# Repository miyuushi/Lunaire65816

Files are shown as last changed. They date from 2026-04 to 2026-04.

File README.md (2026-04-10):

# Lunaire65816

My 16-bit retro computer I designed from scratch. It's centered around a 65816 CPU and uses classic components with FPGA-based glue logic, hardware FM sound, and modern display output.

## Features

- 65816 16-bit CPU
- Custom PCB design
- FPGA for glue logic and video generation
- YM3812 FM synthesis sound chip
- Dual VIA chips for I/O
- SNES controller headers
- PS/2 keyboard interface
- VGA output

## Architecture Overview

- CPU: WDC 65816
- Sound: YM3812 (OPL2)
- I/O: Two VIA chips
- Video: VGA generated using FPGA logic
- Input:
  - SNES controller ports
  - PS/2 keyboard
- Address decoding: GAL
- Board: Custom PCB

## Memory Map

Address decoding is handled by a GAL chip.

### 6502 Emulation Mode

- 48K RAM
- 4K I/O
- 12K ROM

This mode is useful for compatibility and early bring-up.

### 65816 Native Mode

- 4MB RAM
- 4K I/O (expandable, may increase later)
- 12K ROM

Native mode enables the full 24-bit address space of the 65816.

## Audio

The system uses a YM3812 (OPL2) FM synthesis chip for hardware-generated sound.

## Input

- SNES controller headers for gamepad input
- PS/2 keyboard support

## Video (unimplemented)

VGA output is generated through FPGA logic. The goal is compatibility with modern monitors. 

## Screenshots

Hardware:
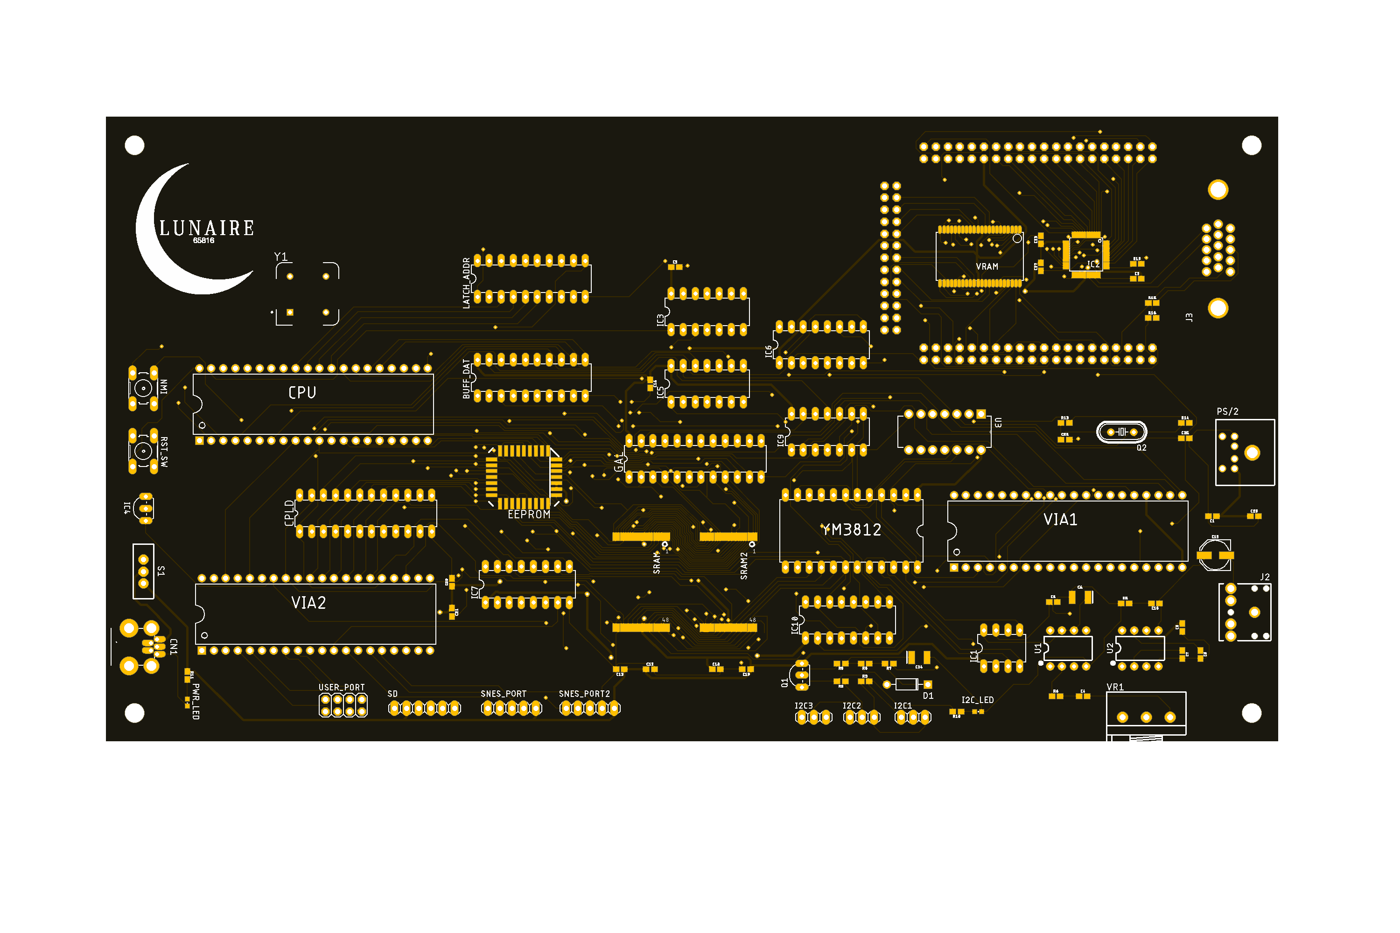
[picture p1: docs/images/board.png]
Board


## Hardware Design Notes

- Custom PCB layout
- Discrete retro components
- FPGA used for glue logic and video
- GAL used for address decoding
- VIA chips provide timers and general-purpose I/O

## Status

Work in progress. Basic hardware is assembled and bring-up is ongoing.

## License

This project is licensed under the GNU Lesser General Public License v3.0 or later.

See the LICENSE file for details.

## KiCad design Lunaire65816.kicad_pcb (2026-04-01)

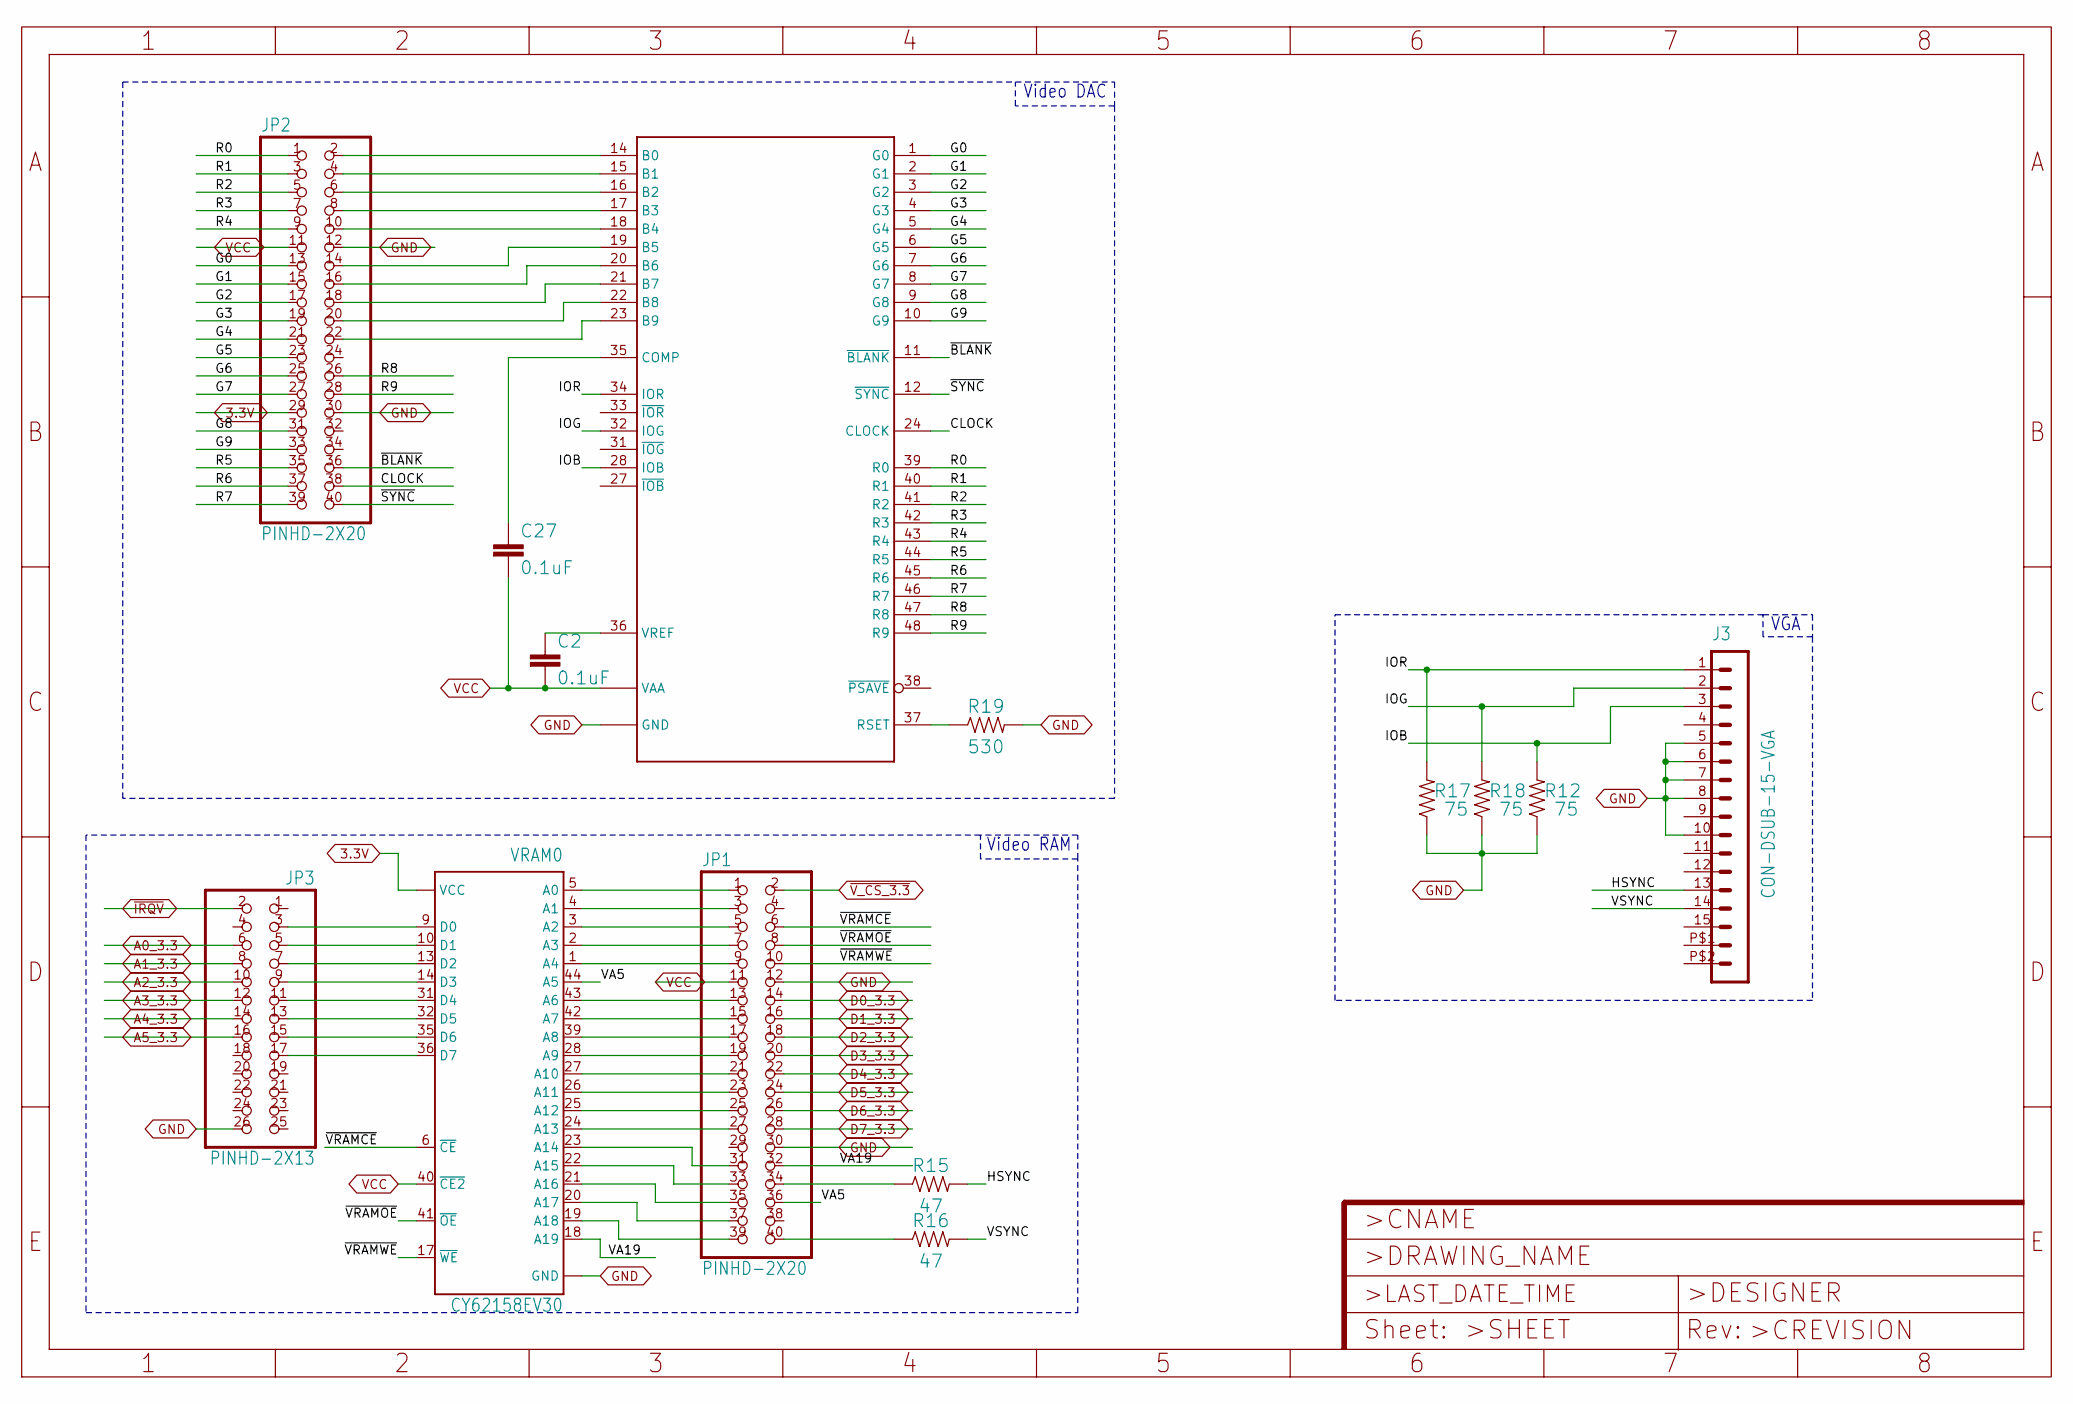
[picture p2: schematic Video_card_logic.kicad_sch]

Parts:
C2, C27: 0.1uF; 0603
IC2: ADV7123; LQFP48
J3: CON-DSUB-15-VGA; 181-015-212-171
JP1, JP2: PINHD-2X20; 2X20
JP3: PINHD-2X13; 2X13
R12, R17, R18: 75; 0603
R15, R16: 47; 0603
R19: 530; 0603
VRAM0: CY62158EV30; TSOP-II-44

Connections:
3.3V: JP2.29, VRAM0.11 (VCC), VRAM0.33 (VCC); also elsewhere on the board
A0_3.3: JP3.6; also elsewhere on the board
A1_3.3: JP3.8; also elsewhere on the board
A2_3.3: JP3.10; also elsewhere on the board
A3_3.3: JP3.12; also elsewhere on the board
A4_3.3: JP3.14; also elsewhere on the board
A5_3.3: JP3.16; also elsewhere on the board
CLOCK: IC2.24 (CLOCK), JP2.38
D0_3.3: JP1.14; also elsewhere on the board
D1_3.3: JP1.16; also elsewhere on the board
D2_3.3: JP1.18; also elsewhere on the board
D3_3.3: JP1.20; also elsewhere on the board
D4_3.3: JP1.22; also elsewhere on the board
D5_3.3: JP1.24; also elsewhere on the board
D6_3.3: JP1.26; also elsewhere on the board
D7_3.3: JP1.28; also elsewhere on the board
G0: IC2.1 (G0), JP2.13
G1: IC2.2 (G1), JP2.15
G2: IC2.3 (G2), JP2.17
G3: IC2.4 (G3), JP2.19
G4: IC2.5 (G4), JP2.21
G5: IC2.6 (G5), JP2.23
G6: IC2.7 (G6), JP2.25
G7: IC2.8 (G7), JP2.27
G8: IC2.9 (G8), JP2.31
G9: IC2.10 (G9), JP2.33
GND: IC2.25 (GND), IC2.26 (GND), J3.5, J3.6, J3.7, J3.8, J3.10, JP1.12, JP1.30, JP2.12, JP2.30, JP3.26, R12.1, R17.1, R18.1, R19.2, VRAM0.12 (GND), VRAM0.34 (GND); also elsewhere on the board
HSYNC: J3.13, R15.2
IOB: IC2.28 (IOB), J3.3, R12.2
IOG: IC2.32 (IOG), J3.2, R18.2
IOR: IC2.34 (IOR), J3.1, R17.2
unnamed: JP1.35, VRAM0.21 (A16)
unnamed: JP1.33, VRAM0.22 (A15)
unnamed: JP1.31, VRAM0.23 (A14)
unnamed: JP1.27, VRAM0.24 (A13)
unnamed: IC2.37 (RSET), R19.1
unnamed: C2.1, IC2.36 (VREF)
unnamed: JP1.37, VRAM0.20 (A17)
unnamed: IC2.14 (B0), JP2.2
unnamed: IC2.15 (B1), JP2.4
unnamed: IC2.16 (B2), JP2.6
unnamed: IC2.17 (B3), JP2.8
unnamed: IC2.18 (B4), JP2.10
unnamed: IC2.19 (B5), JP2.14
unnamed: IC2.20 (B6), JP2.16
unnamed: IC2.21 (B7), JP2.18
unnamed: IC2.22 (B8), JP2.20
unnamed: IC2.23 (B9), JP2.22
unnamed: C27.1, IC2.35 (COMP)
unnamed: JP1.40, R16.1
unnamed: JP1.34, R15.1
unnamed: JP1.25, VRAM0.25 (A12)
unnamed: JP1.23, VRAM0.26 (A11)
unnamed: JP1.21, VRAM0.27 (A10)
unnamed: JP1.19, VRAM0.28 (A9)
unnamed: JP1.17, VRAM0.39 (A8)
unnamed: JP1.15, VRAM0.42 (A7)
unnamed: JP1.13, VRAM0.43 (A6)
unnamed: JP1.9, VRAM0.1 (A4)
unnamed: JP1.7, VRAM0.2 (A3)
unnamed: JP1.5, VRAM0.3 (A2)
unnamed: JP3.17, VRAM0.36 (D7)
unnamed: JP3.15, VRAM0.35 (D6)
unnamed: JP3.13, VRAM0.32 (D5)
unnamed: JP3.11, VRAM0.31 (D4)
unnamed: JP3.9, VRAM0.14 (D3)
unnamed: JP3.7, VRAM0.13 (D2)
unnamed: JP3.5, VRAM0.10 (D1)
unnamed: JP3.3, VRAM0.9 (D0)
unnamed: JP1.39, VRAM0.19 (A18)
unnamed: JP1.3, VRAM0.4 (A1)
unnamed: JP1.1, VRAM0.5 (A0)
R0: IC2.39 (R0), JP2.1
R1: IC2.40 (R1), JP2.3
R2: IC2.41 (R2), JP2.5
R3: IC2.42 (R3), JP2.7
R4: IC2.43 (R4), JP2.9
R5: IC2.44 (R5), JP2.35
R6: IC2.45 (R6), JP2.37
R7: IC2.46 (R7), JP2.39
R8: IC2.47 (R8), JP2.26
R9: IC2.48 (R9), JP2.28
VA5: JP1.36, VRAM0.44 (A5)
VA19: JP1.32, VRAM0.18 (A19)
VCC: C2.2, C27.2, IC2.13 (VAA), IC2.29 (VAA), IC2.30 (VAA), JP1.11, JP2.11, VRAM0.40 (~CE2); also elsewhere on the board
VSYNC: J3.14, R16.2
~BLANK: IC2.11 (~BLANK), JP2.36
~IRQV: JP3.2; also elsewhere on the board
~SYNC: IC2.12 (~SYNC), JP2.40
~VRAMCE: JP1.6, VRAM0.6 (~CE)
~VRAMOE: JP1.8, VRAM0.41 (~OE)
~VRAMWE: JP1.10, VRAM0.17 (~WE)
~V_CS_3.3: JP1.2; also elsewhere on the board

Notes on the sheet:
VGA
Video DAC
Video RAM

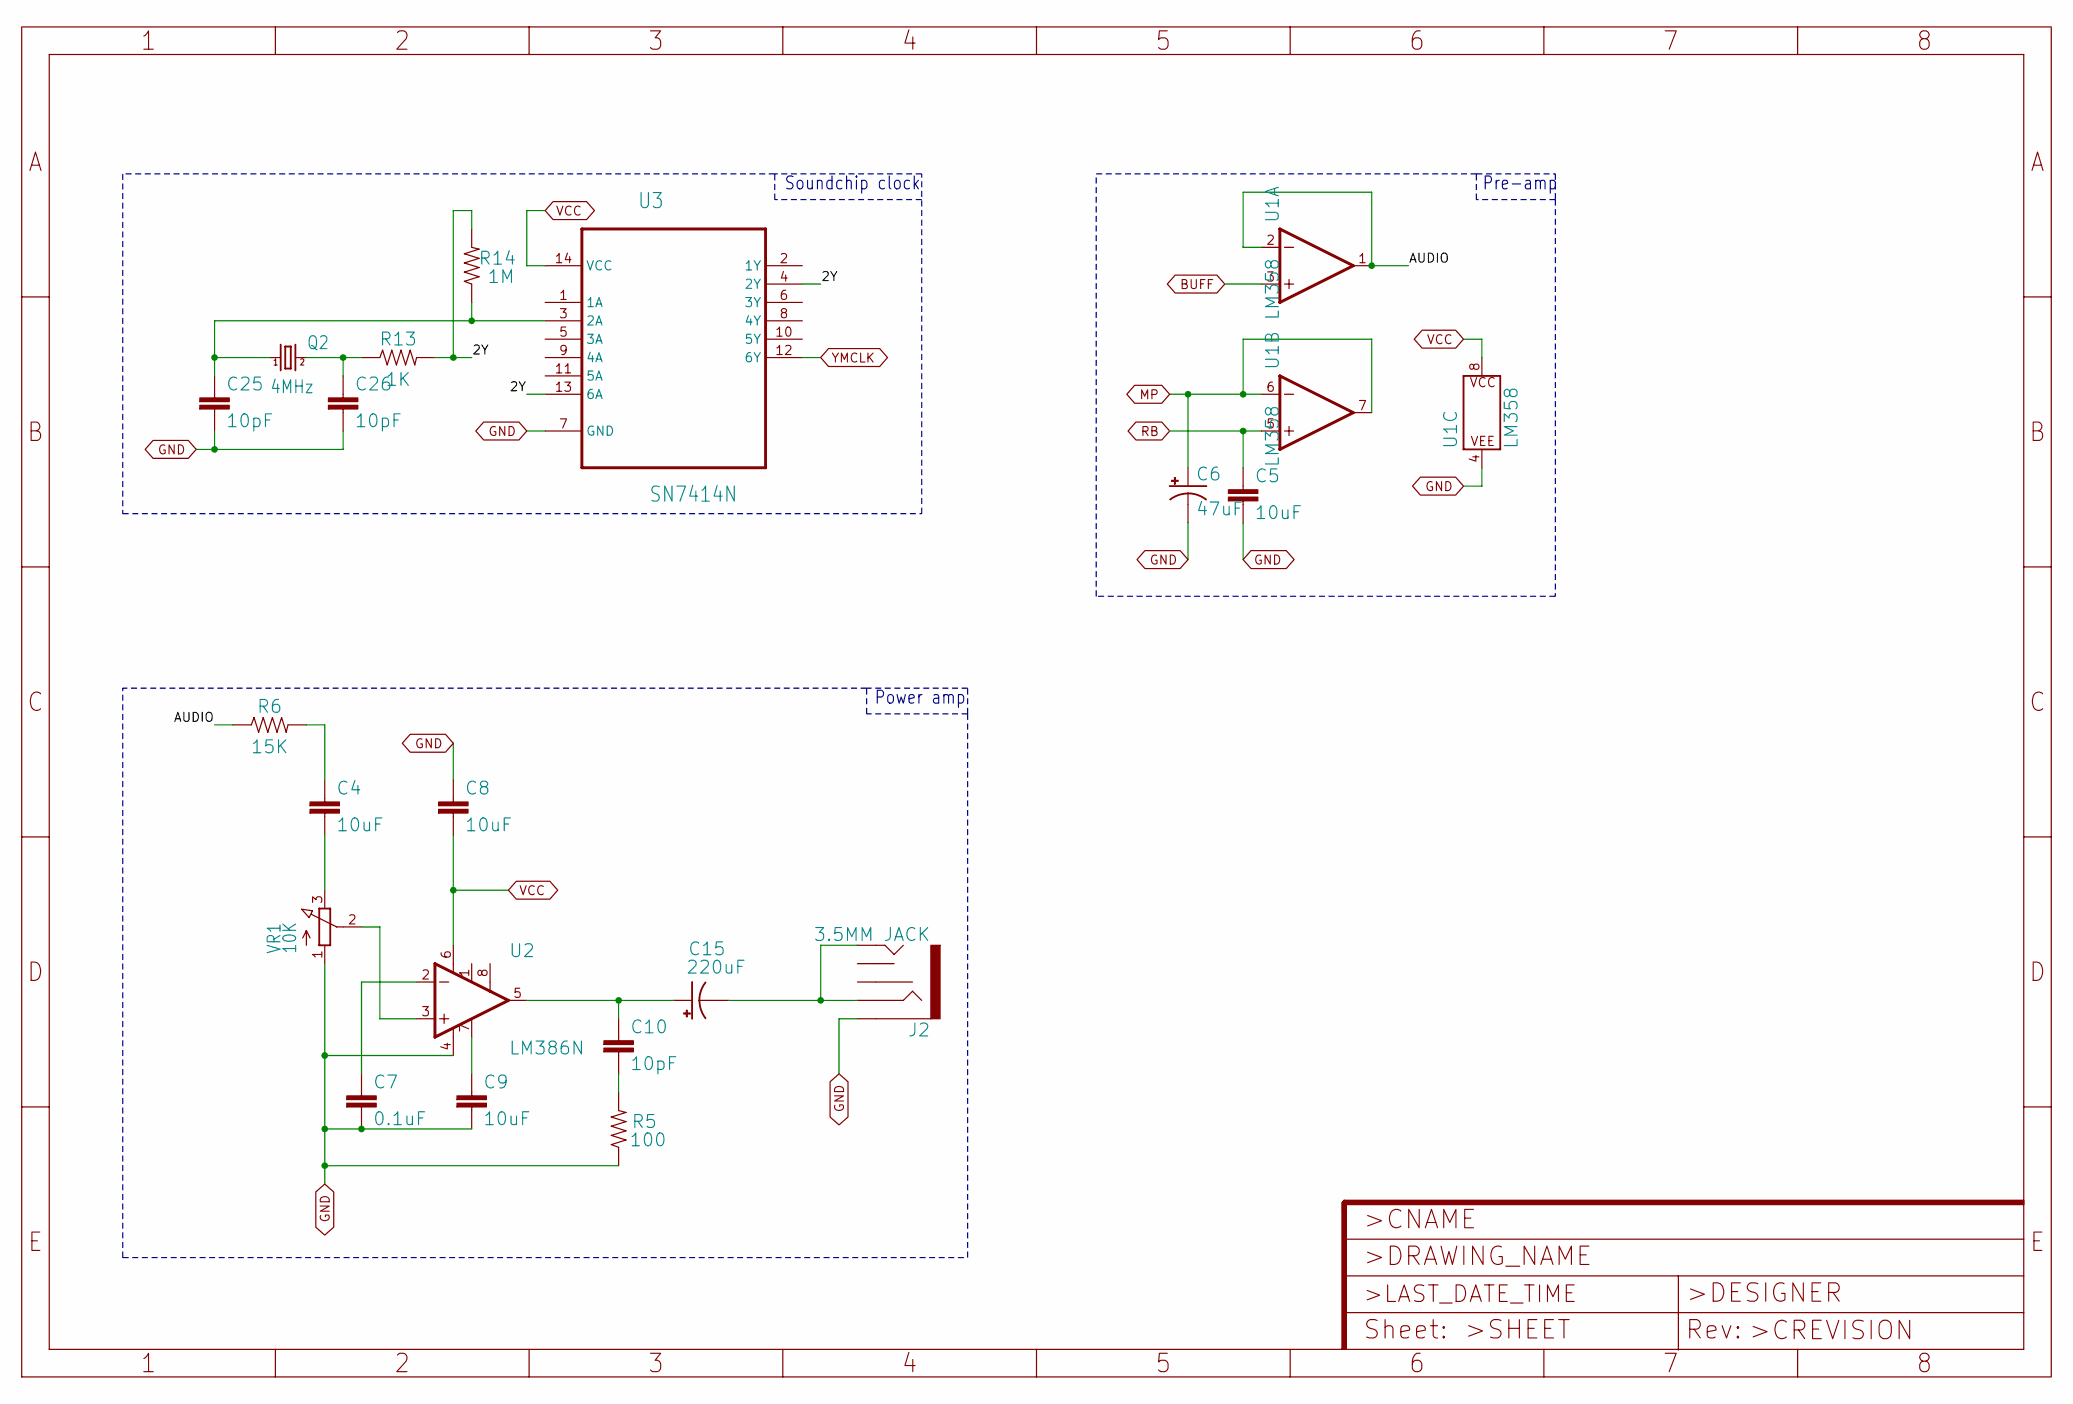
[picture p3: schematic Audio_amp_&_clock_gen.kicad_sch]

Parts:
C4, C5, C8, C9: 10uF; 0603
C6: 47uF; EIA3528
C7: 0.1uF; 0603
C10, C25, C26: 10pF; 0603
C15: 220uF; PANASONIC_D
J2: 3.5MM JACK; AUDIO-JACK
Q2: 4MHz; HC49_S
R5: 100; 0603
R6: 15K; 0603
R13: 1K; 0603
R14: 1M; 0603
U1: LM358; DIP08
U2: LM386N; DIP08
U3: SN7414N; DIP254P762X508-14
VR1: 10K; 3RP_1610N

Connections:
2Y: R13.2, R14.2, U3.4 (2Y), U3.13 (6A)
AUDIO: R6.1, U1.1 (OUT), U1.2 (-IN)
BUFF: U1.3 (+IN); also elsewhere on the board
GND: C5.2, C6.C (-), C7.2, C8.1, C9.2, C25.2, C26.2, J2.SLEEVE, R5.1, U1.4 (P$V-), U2.4 (V-), U3.7 (GND), VR1.1 (A); also elsewhere on the board
MP: C6.A (+), U1.6 (-IN), U1.7 (OUT); also elsewhere on the board
unnamed: C7.1, U2.2 (-IN)
unnamed: C4.1, R6.2
unnamed: C4.2, VR1.3 (E)
unnamed: U2.3 (+IN), VR1.2 (S)
unnamed: C9.1, U2.7 (BP)
unnamed: C10.1, C15.+, U2.5 (OUT)
unnamed: C10.2, R5.2
unnamed: C15.-, J2.RING, J2.TIP
unnamed: C25.1, Q2.1, R14.1, U3.3 (2A)
unnamed: C26.1, Q2.2, R13.1
RB: C5.1, U1.5 (+IN); also elsewhere on the board
VCC: C8.2, U1.8 (P$V+), U2.6 (V+), U3.14 (VCC); also elsewhere on the board
YMCLK: U3.12 (6Y); also elsewhere on the board

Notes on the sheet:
Power amp
Soundchip clock
Pre-amp

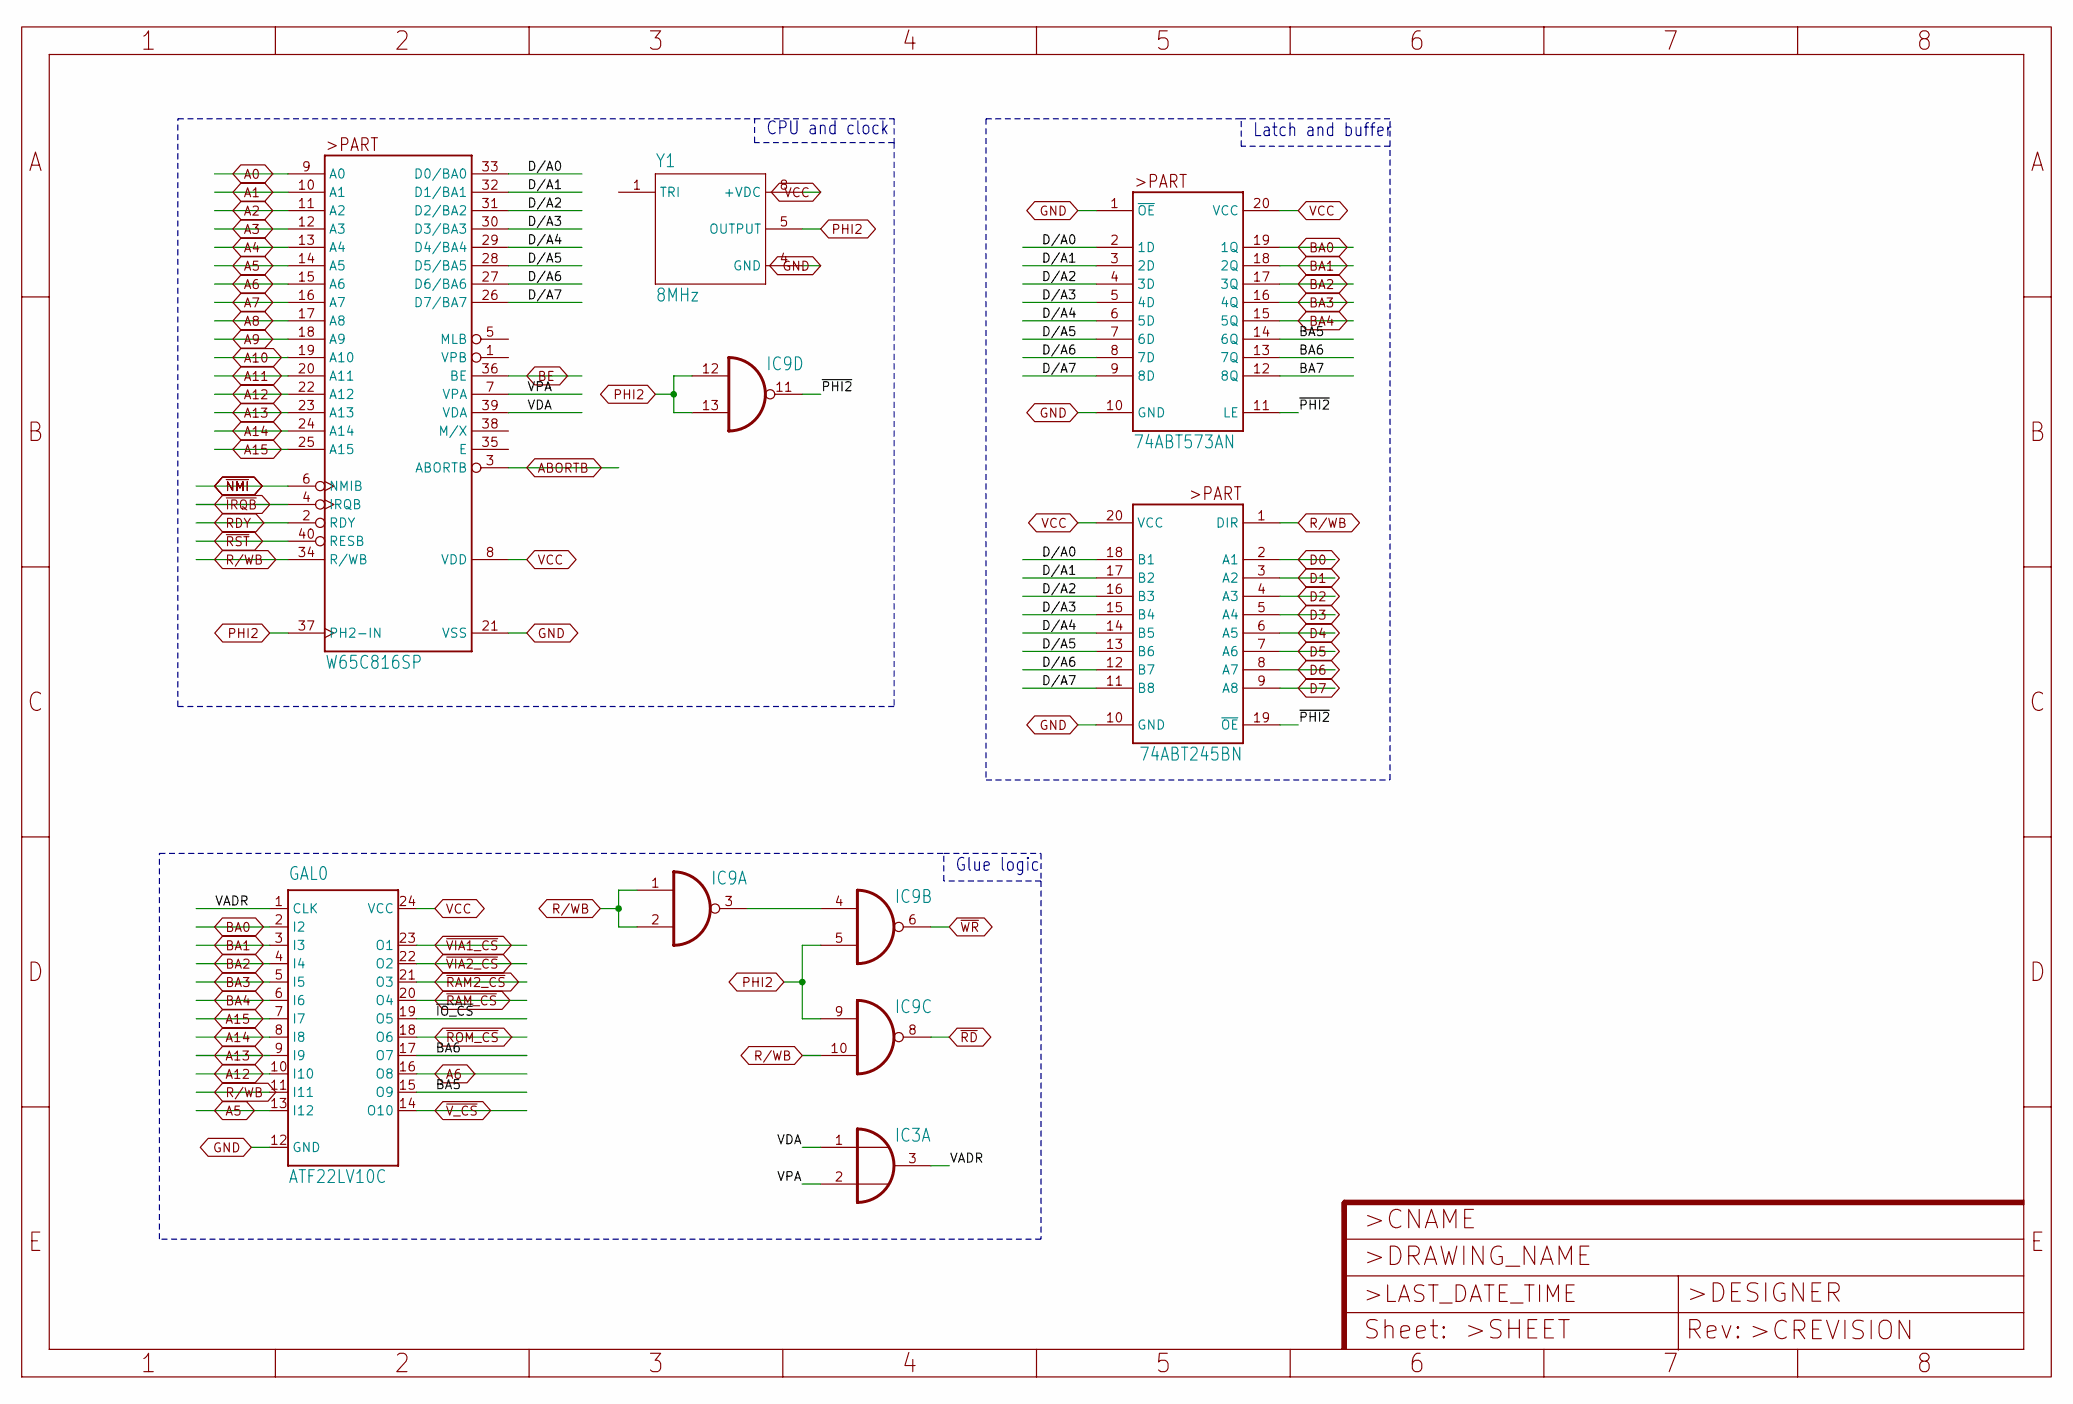
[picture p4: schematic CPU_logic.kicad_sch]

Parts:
BUFF_DAT0: 74ABT245BN; PDIP20
CPU0: W65C816SP; DIP-40
GAL0: ATF22LV10C; DIL24-3
IC3: 7432N; DIL14
IC9: 7400N; DIL14
LATCH_ADDR0: 74ABT573AN; PDIP20
Y1: 8MHz; OSC_ECS-2200B-110.5

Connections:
A0: CPU0.9 (A0); also elsewhere on the board
A1: CPU0.10 (A1); also elsewhere on the board
A2: CPU0.11 (A2); also elsewhere on the board
A3: CPU0.12 (A3); also elsewhere on the board
A4: CPU0.13 (A4); also elsewhere on the board
A5: CPU0.14 (A5), GAL0.13 (I12); also elsewhere on the board
A6: CPU0.15 (A6), GAL0.16 (O8); also elsewhere on the board
A7: CPU0.16 (A7); also elsewhere on the board
A8: CPU0.17 (A8); also elsewhere on the board
A9: CPU0.18 (A9); also elsewhere on the board
A10: CPU0.19 (A10); also elsewhere on the board
A11: CPU0.20 (A11); also elsewhere on the board
A12: CPU0.22 (A12), GAL0.10 (I10); also elsewhere on the board
A13: CPU0.23 (A13), GAL0.9 (I9); also elsewhere on the board
A14: CPU0.24 (A14), GAL0.8 (I8); also elsewhere on the board
A15: CPU0.25 (A15), GAL0.7 (I7); also elsewhere on the board
ABORTB: CPU0.3 (ABORTB); also elsewhere on the board
BA0: GAL0.2 (I2), LATCH_ADDR0.19 (1Q); also elsewhere on the board
BA1: GAL0.3 (I3), LATCH_ADDR0.18 (2Q); also elsewhere on the board
BA2: GAL0.4 (I4), LATCH_ADDR0.17 (3Q); also elsewhere on the board
BA3: GAL0.5 (I5), LATCH_ADDR0.16 (4Q); also elsewhere on the board
BA4: GAL0.6 (I6), LATCH_ADDR0.15 (5Q); also elsewhere on the board
BA5: GAL0.15 (O9), LATCH_ADDR0.14 (6Q)
BA6: GAL0.17 (O7), LATCH_ADDR0.13 (7Q)
BA7: LATCH_ADDR0.12 (8Q)
BE: CPU0.36 (BE); also elsewhere on the board
D0: BUFF_DAT0.2 (A1); also elsewhere on the board
D1: BUFF_DAT0.3 (A2); also elsewhere on the board
D2: BUFF_DAT0.4 (A3); also elsewhere on the board
D3: BUFF_DAT0.5 (A4); also elsewhere on the board
D4: BUFF_DAT0.6 (A5); also elsewhere on the board
D5: BUFF_DAT0.7 (A6); also elsewhere on the board
D6: BUFF_DAT0.8 (A7); also elsewhere on the board
D7: BUFF_DAT0.9 (A8); also elsewhere on the board
D/A0: BUFF_DAT0.18 (B1), CPU0.33 (D0/BA0), LATCH_ADDR0.2 (1D)
D/A1: BUFF_DAT0.17 (B2), CPU0.32 (D1/BA1), LATCH_ADDR0.3 (2D)
D/A2: BUFF_DAT0.16 (B3), CPU0.31 (D2/BA2), LATCH_ADDR0.4 (3D)
D/A3: BUFF_DAT0.15 (B4), CPU0.30 (D3/BA3), LATCH_ADDR0.5 (4D)
D/A4: BUFF_DAT0.14 (B5), CPU0.29 (D4/BA4), LATCH_ADDR0.6 (5D)
D/A5: BUFF_DAT0.13 (B6), CPU0.28 (D5/BA5), LATCH_ADDR0.7 (6D)
D/A6: BUFF_DAT0.12 (B7), CPU0.27 (D6/BA6), LATCH_ADDR0.8 (7D)
D/A7: BUFF_DAT0.11 (B8), CPU0.26 (D7/BA7), LATCH_ADDR0.9 (8D)
GND: BUFF_DAT0.10 (GND), CPU0.21 (VSS), GAL0.12 (GND), IC3.7 (GND), IC9.7 (GND), LATCH_ADDR0.1 (~OE), LATCH_ADDR0.10 (GND), Y1.4 (GND); also elsewhere on the board
unnamed: IC9.3 (O), IC9.4 (I0)
PHI2: CPU0.37 (PH2-IN), IC9.5 (I1), IC9.9 (I0), IC9.12 (I0), IC9.13 (I1), Y1.5 (OUTPUT); also elsewhere on the board
R/WB: BUFF_DAT0.1 (DIR), CPU0.34 (R/WB), GAL0.11 (I11), IC9.1 (I0), IC9.2 (I1), IC9.10 (I1); also elsewhere on the board
RDY: CPU0.2 (RDY); also elsewhere on the board
VADR: GAL0.1 (CLK), IC3.3 (O)
VCC: BUFF_DAT0.20 (VCC), CPU0.8 (VDD), GAL0.24 (VCC), IC3.14 (VCC), IC9.14 (VCC), LATCH_ADDR0.20 (VCC), Y1.8 (+VDC); also elsewhere on the board
VDA: CPU0.39 (VDA), IC3.1 (I0)
VPA: CPU0.7 (VPA), IC3.2 (I1)
~IO_CS: GAL0.19 (O5)
~IRQB: CPU0.4 (IRQB); also elsewhere on the board
~NMI: CPU0.6 (NMIB); also elsewhere on the board
~PHI2: BUFF_DAT0.19 (~OE), IC9.11 (O), LATCH_ADDR0.11 (LE)
~RAM2_CS: GAL0.21 (O3); also elsewhere on the board
~RAM_CS: GAL0.20 (O4); also elsewhere on the board
~RD: IC9.8 (O); also elsewhere on the board
~ROM_CS: GAL0.18 (O6); also elsewhere on the board
~RST: CPU0.40 (RESB); also elsewhere on the board
~VIA1_CS: GAL0.23 (O1); also elsewhere on the board
~VIA2_CS: GAL0.22 (O2); also elsewhere on the board
~V_CS: GAL0.14 (O10); also elsewhere on the board
~WR: IC9.6 (O); also elsewhere on the board

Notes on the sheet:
CPU and clock
Latch and buffer
Glue logic

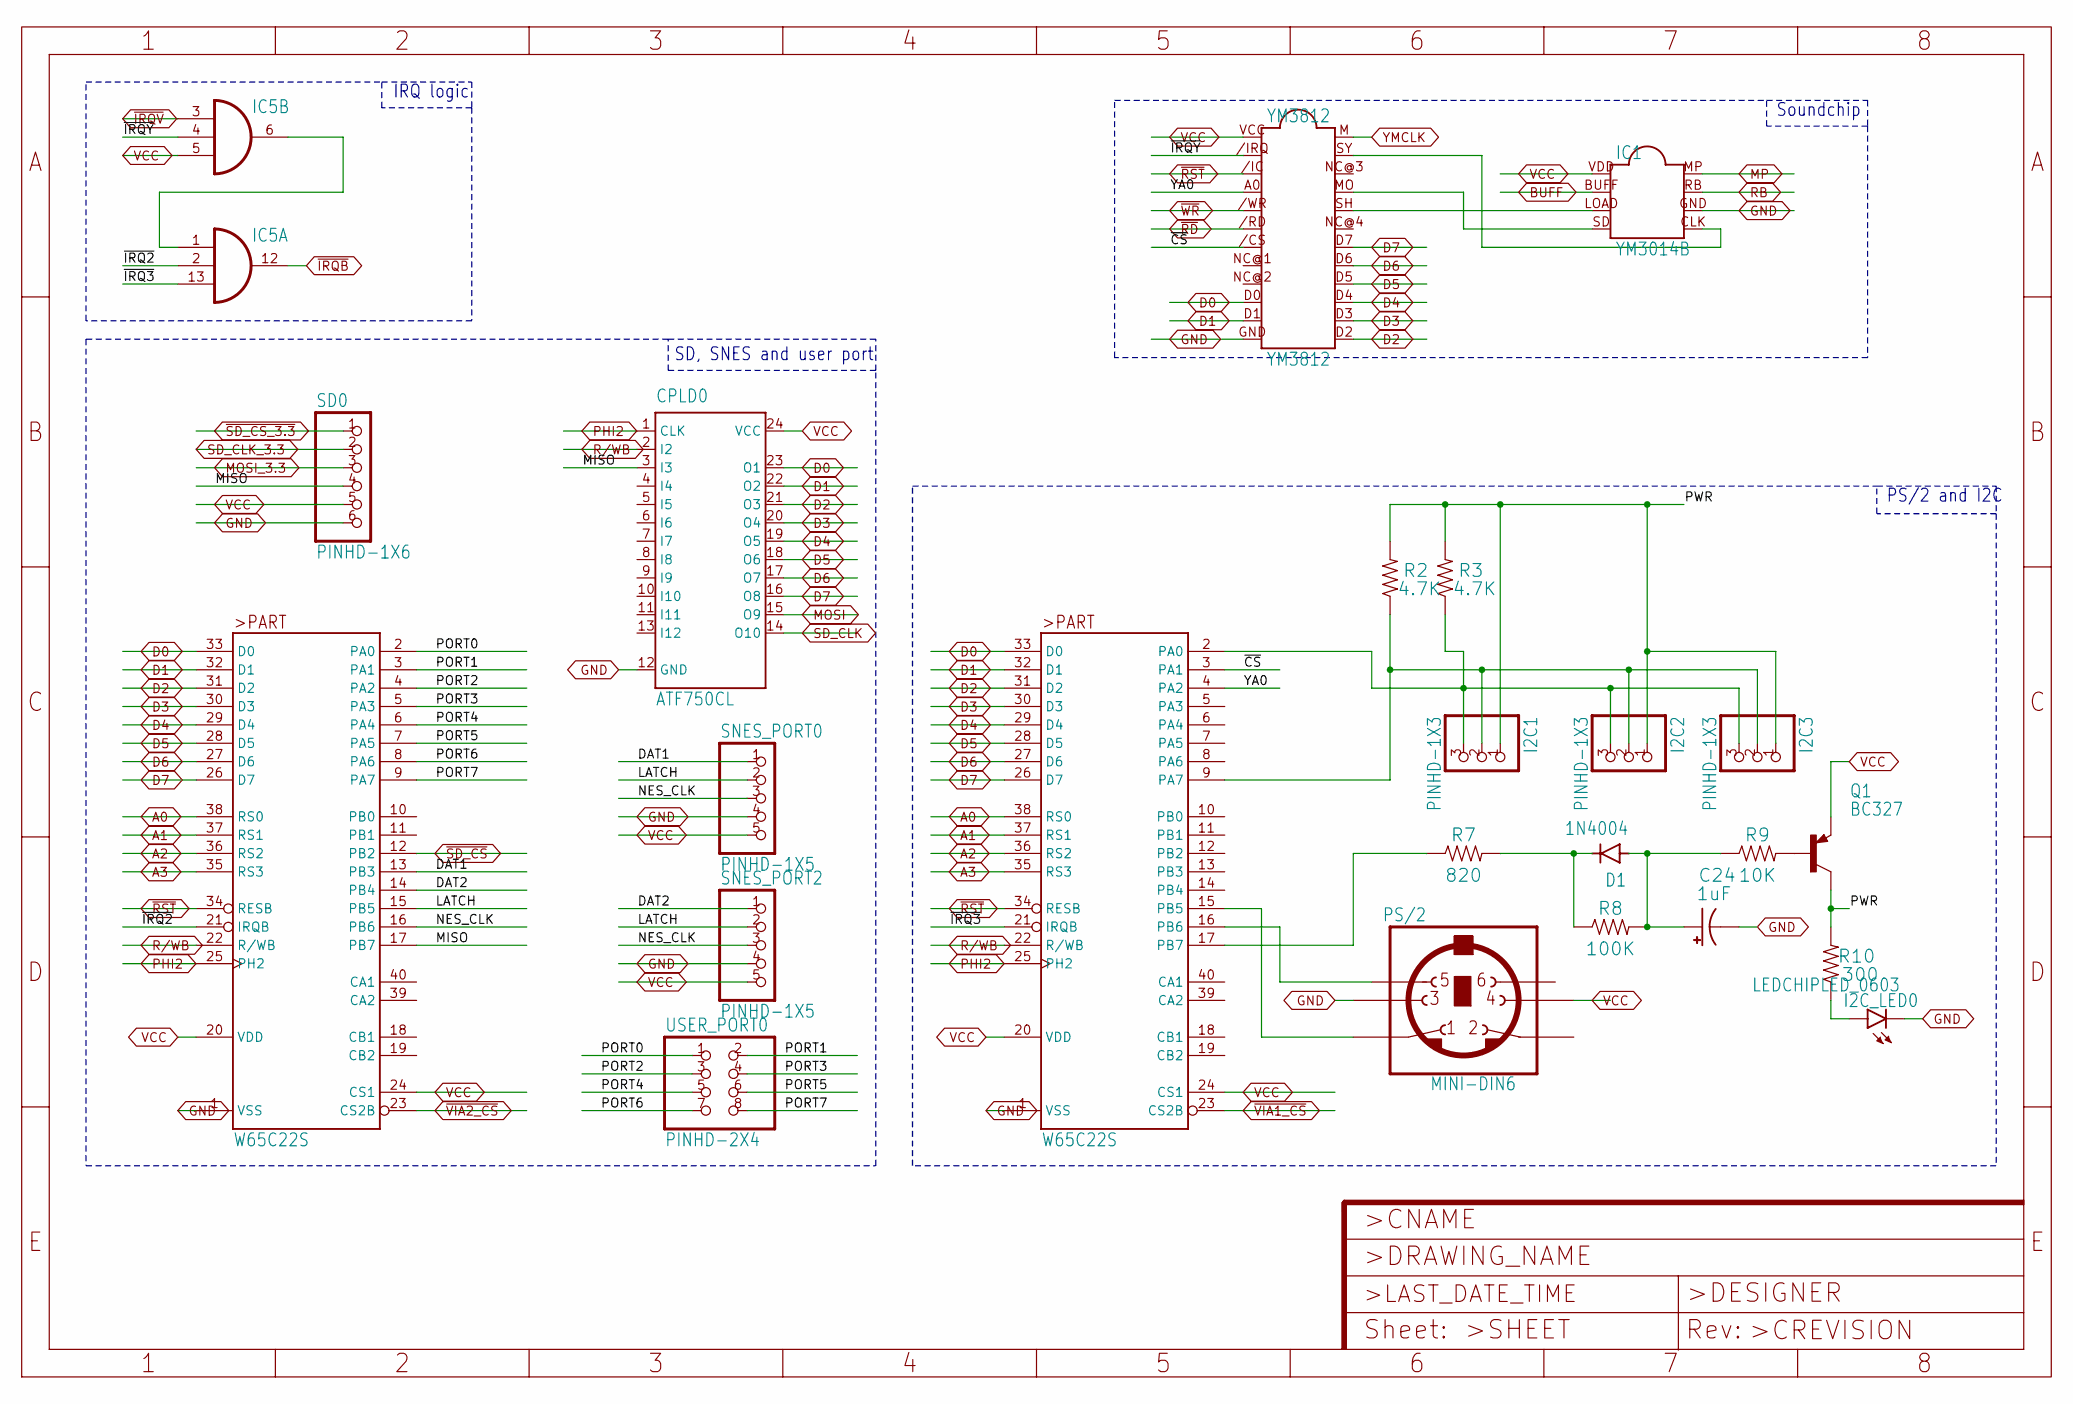
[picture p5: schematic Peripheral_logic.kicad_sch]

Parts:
C24: 1uF; EIA3528
CPLD0: ATF750CL; DIL24-3
D1: 1N4004; DO-41
I2C1, I2C2, I2C3: PINHD-1X3; 1X03
I2C_LED0: LEDCHIPLED_0603; CHIPLED_0603
IC1: YM3014B
IC5: 7411N; DIL14
PS/2: MINI-DIN6
Q1: BC327; TO92-EBC
R2, R3: 4.7K; 0603
R7: 820; 0603
R8: 100K; 0603
R9: 10K; 0603
R10: 300; 0603
SD0: PINHD-1X6; 1X06
SNES_PORT0, SNES_PORT2: PINHD-1X5; 1X05
USER_PORT0: PINHD-2X4; 2X04
VIA1, VIA2: W65C22S; DIP-40
YM3812: YM3812

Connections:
A0: VIA1.38 (RS0), VIA2.38 (RS0); also elsewhere on the board
A1: VIA1.37 (RS1), VIA2.37 (RS1); also elsewhere on the board
A2: VIA1.36 (RS2), VIA2.36 (RS2); also elsewhere on the board
A3: VIA1.35 (RS3), VIA2.35 (RS3); also elsewhere on the board
BUFF: IC1.BUFF; also elsewhere on the board
CLK: I2C1.3, I2C2.3, I2C3.3, R3.1, VIA1.2 (PA0)
D0: CPLD0.23 (O1), VIA1.33 (D0), VIA2.33 (D0), YM3812.D0; also elsewhere on the board
D1: CPLD0.22 (O2), VIA1.32 (D1), VIA2.32 (D1), YM3812.D1; also elsewhere on the board
D2: CPLD0.21 (O3), VIA1.31 (D2), VIA2.31 (D2), YM3812.D2; also elsewhere on the board
D3: CPLD0.20 (O4), VIA1.30 (D3), VIA2.30 (D3), YM3812.D3; also elsewhere on the board
D4: CPLD0.19 (O5), VIA1.29 (D4), VIA2.29 (D4), YM3812.D4; also elsewhere on the board
D5: CPLD0.18 (O6), VIA1.28 (D5), VIA2.28 (D5), YM3812.D5; also elsewhere on the board
D6: CPLD0.17 (O7), VIA1.27 (D6), VIA2.27 (D6), YM3812.D6; also elsewhere on the board
D7: CPLD0.16 (O8), VIA1.26 (D7), VIA2.26 (D7), YM3812.D7; also elsewhere on the board
DAT1: SNES_PORT0.1, VIA2.13 (PB3)
DAT2: SNES_PORT2.1, VIA2.14 (PB4)
DATA: I2C1.2, I2C2.2, I2C3.2, R2.1, VIA1.9 (PA7)
GND: C24.C (-), CPLD0.12 (GND), I2C_LED0.C, IC1.GND, IC5.7 (GND), PS/2.3, SD0.6, SNES_PORT0.4, SNES_PORT2.4, VIA1.1 (VSS), VIA2.1 (VSS), YM3812.GND; also elsewhere on the board
LATCH: SNES_PORT0.2, SNES_PORT2.2, VIA2.15 (PB5)
MISO: CPLD0.3 (I3), SD0.4, VIA2.17 (PB7)
MOSI: CPLD0.15 (O9); also elsewhere on the board
MOSI_3.3: SD0.3; also elsewhere on the board
MP: IC1.MP; also elsewhere on the board
unnamed: IC1.LOAD, YM3812.SH
unnamed: IC1.SD, YM3812.MO
unnamed: PS/2.1, VIA1.15 (PB5)
unnamed: PS/2.5, VIA1.16 (PB6)
unnamed: R7.1, VIA1.17 (PB7)
unnamed: D1.C, R7.2, R8.1
unnamed: C24.A (+), D1.A, R8.2, R9.1
unnamed: Q1.B, R9.2
unnamed: I2C_LED0.A, R10.1
unnamed: IC1.CLK, YM3812.SY
unnamed: IC5.1 (I0), IC5.6 (O)
NES_CLK: SNES_PORT0.3, SNES_PORT2.3, VIA2.16 (PB6)
PHI2: CPLD0.1 (CLK), VIA1.25 (PH2), VIA2.25 (PH2); also elsewhere on the board
PORT0: USER_PORT0.1, VIA2.2 (PA0)
PORT1: USER_PORT0.2, VIA2.3 (PA1)
PORT2: USER_PORT0.3, VIA2.4 (PA2)
PORT3: USER_PORT0.4, VIA2.5 (PA3)
PORT4: USER_PORT0.5, VIA2.6 (PA4)
PORT5: USER_PORT0.6, VIA2.7 (PA5)
PORT6: USER_PORT0.7, VIA2.8 (PA6)
PORT7: USER_PORT0.8, VIA2.9 (PA7)
PWR: I2C1.1, I2C2.1, I2C3.1, Q1.C, R2.2, R3.2, R10.2
R/WB: CPLD0.2 (I2), VIA1.22 (R/WB), VIA2.22 (R/WB); also elsewhere on the board
RB: IC1.RB; also elsewhere on the board
SD_CLK: CPLD0.14 (O10); also elsewhere on the board
SD_CLK_3.3: SD0.2; also elsewhere on the board
VCC: CPLD0.24 (VCC), IC1.VDD, IC5.5 (I2), IC5.14 (VCC), PS/2.4, Q1.E, SD0.5, SNES_PORT0.5, SNES_PORT2.5, VIA1.20 (VDD), VIA1.24 (CS1), VIA2.20 (VDD), VIA2.24 (CS1), YM3812.VCC; also elsewhere on the board
YA0: VIA1.4 (PA2), YM3812.A0
YMCLK: YM3812.M; also elsewhere on the board
~CS: VIA1.3 (PA1), YM3812./CS
~IRQ2: IC5.2 (I1), VIA2.21 (IRQB)
~IRQ3: IC5.13 (I2), VIA1.21 (IRQB)
~IRQB: IC5.12 (O); also elsewhere on the board
~IRQV: IC5.3 (I0); also elsewhere on the board
~IRQY: IC5.4 (I1), YM3812./IRQ
~RD: YM3812./RD; also elsewhere on the board
~RST: VIA1.34 (RESB), VIA2.34 (RESB), YM3812./IC; also elsewhere on the board
~SD_CS_3.3: SD0.1; also elsewhere on the board
~SD_CS: VIA2.12 (PB2); also elsewhere on the board
~VIA1_CS: VIA1.23 (CS2B); also elsewhere on the board
~VIA2_CS: VIA2.23 (CS2B); also elsewhere on the board
~WR: YM3812./WR; also elsewhere on the board

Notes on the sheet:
Soundchip
SD, SNES and user port
PS/2 and I2C
IRQ logic

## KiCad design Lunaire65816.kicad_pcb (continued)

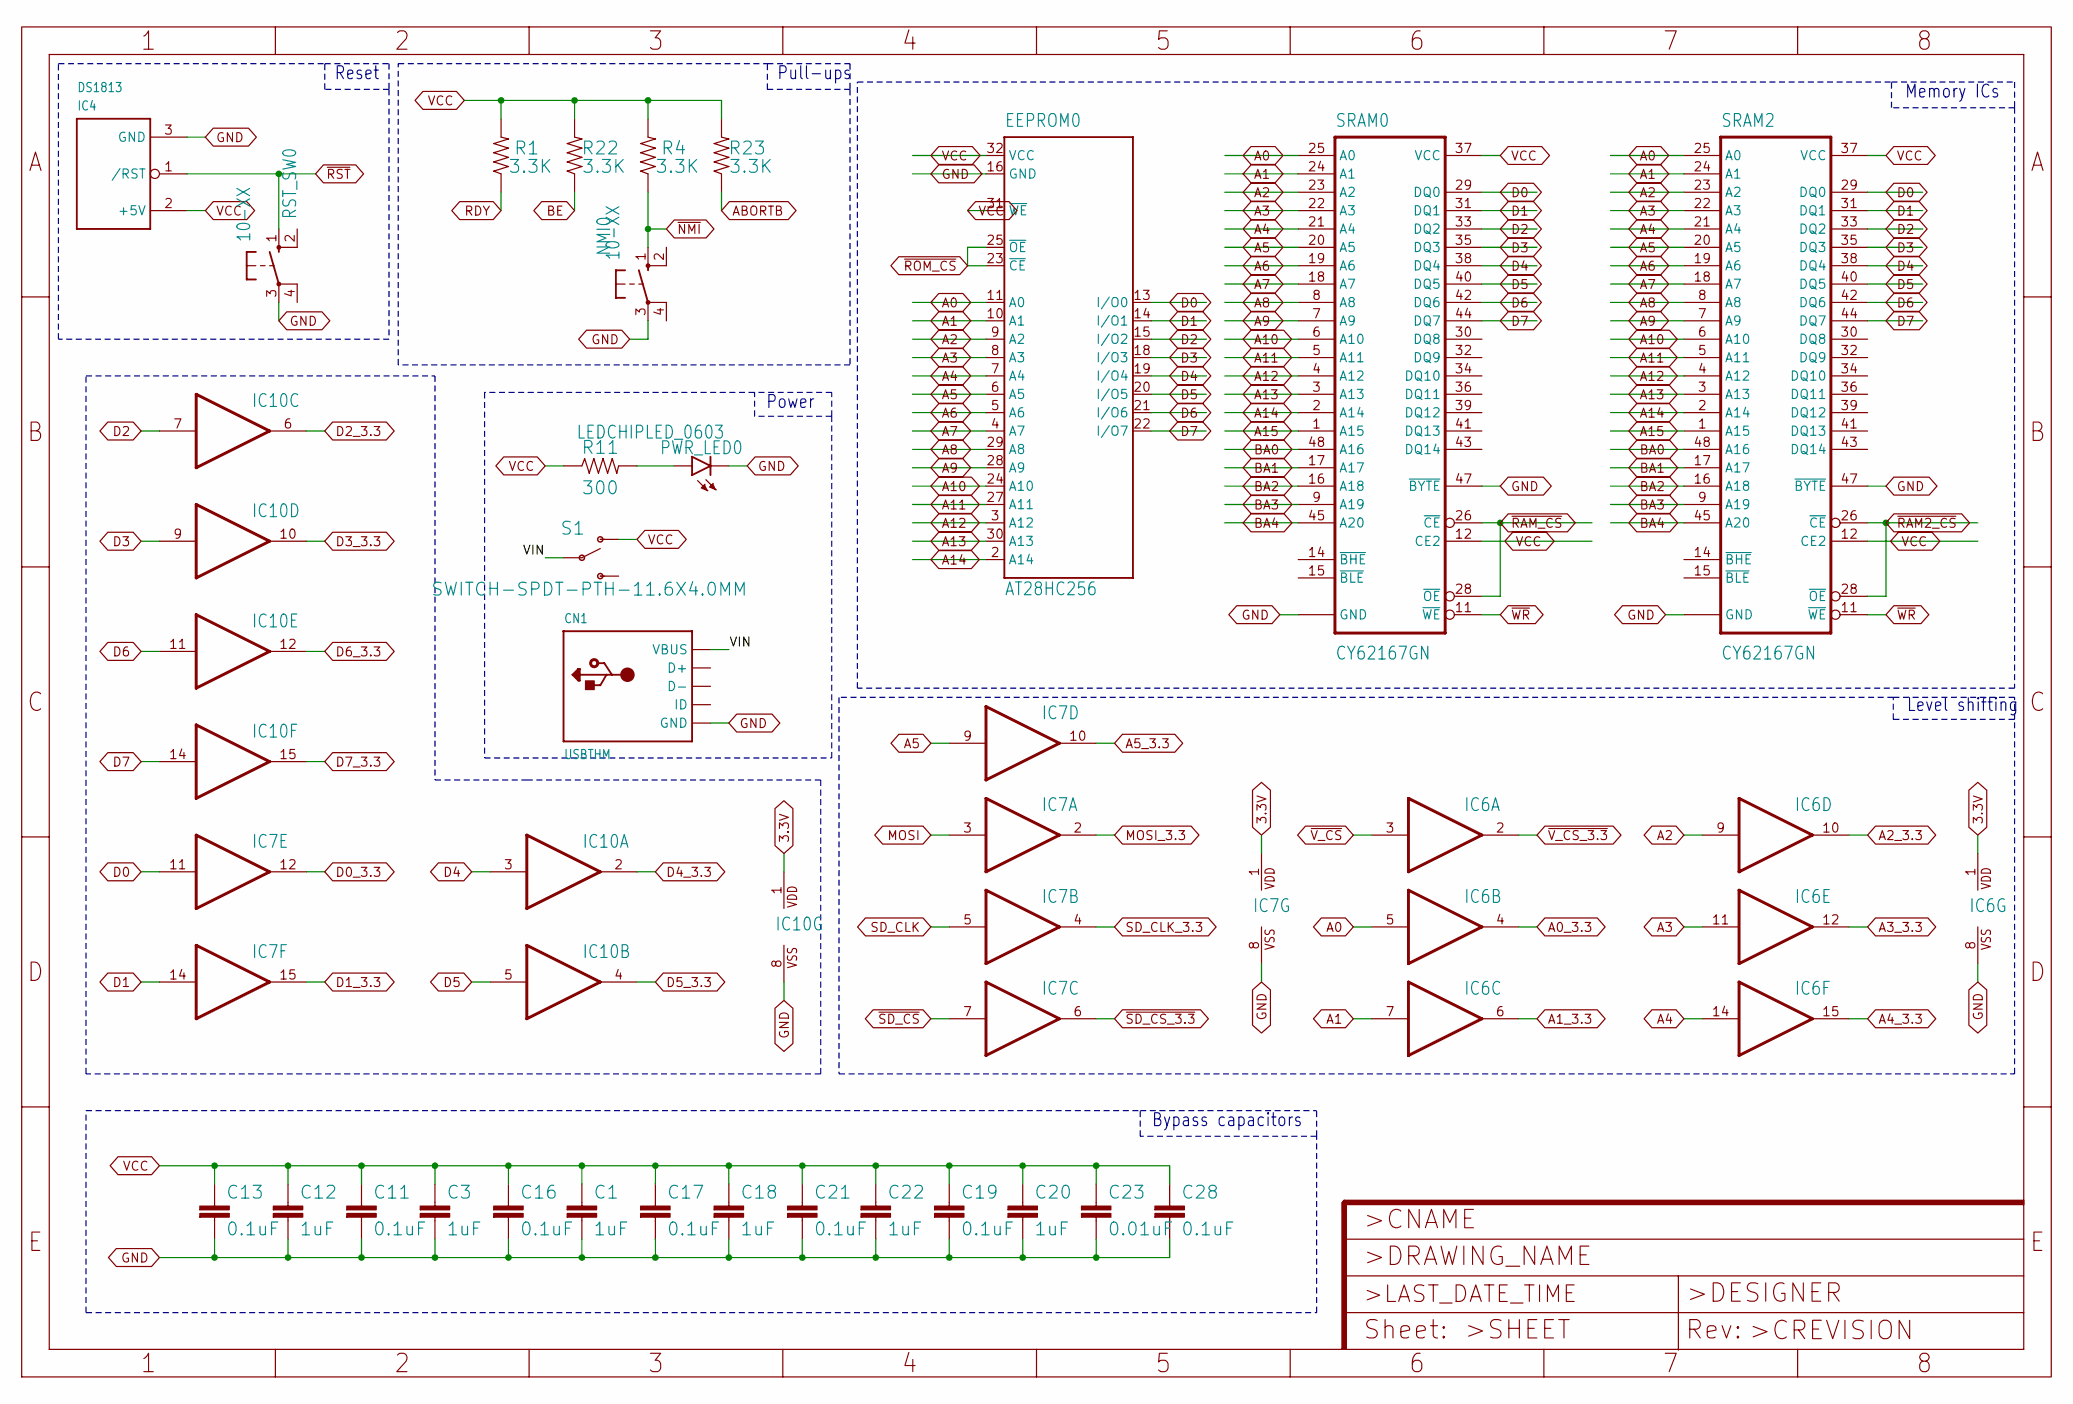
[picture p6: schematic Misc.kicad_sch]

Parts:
C1, C3, C12, C18, C20, C22: 1uF; 0603
C11, C13, C16, C17, C19, C21, C28: 0.1uF; 0603
C23: 0.01uF; 0603
CN1: USBTHM; USB-MINIB-THM
EEPROM0: AT28HC256; PLCC-32
IC4: DS1813; TO-92
IC6, IC7, IC10: 4050N; DIL16
NMI0: 10-XX; B3F-10XX
PWR_LED0: LEDCHIPLED_0603; CHIPLED_0603
R1, R4, R22, R23: 3.3K; 0603
R11: 300; 0603
RST_SW0: 10-XX; B3F-10XX
S1: SWITCH-SPDT-PTH-11.6X4.0MM; SWITCH_SPDT_PTH_11.6X4.0MM
SRAM0, SRAM2: CY62167GN; TSOP48

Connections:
3.3V: IC6.1 (VDD), IC7.1 (VDD), IC10.1 (VDD); also elsewhere on the board
A0: EEPROM0.11 (A0), IC6.5 (I), SRAM0.25 (A0), SRAM2.25 (A0); also elsewhere on the board
A0_3.3: IC6.4 (O); also elsewhere on the board
A1: EEPROM0.10 (A1), IC6.7 (I), SRAM0.24 (A1), SRAM2.24 (A1); also elsewhere on the board
A1_3.3: IC6.6 (O); also elsewhere on the board
A2: EEPROM0.9 (A2), IC6.9 (I), SRAM0.23 (A2), SRAM2.23 (A2); also elsewhere on the board
A2_3.3: IC6.10 (O); also elsewhere on the board
A3: EEPROM0.8 (A3), IC6.11 (I), SRAM0.22 (A3), SRAM2.22 (A3); also elsewhere on the board
A3_3.3: IC6.12 (O); also elsewhere on the board
A4: EEPROM0.7 (A4), IC6.14 (I), SRAM0.21 (A4), SRAM2.21 (A4); also elsewhere on the board
A4_3.3: IC6.15 (O); also elsewhere on the board
A5: EEPROM0.6 (A5), IC7.9 (I), SRAM0.20 (A5), SRAM2.20 (A5); also elsewhere on the board
A5_3.3: IC7.10 (O); also elsewhere on the board
A6: EEPROM0.5 (A6), SRAM0.19 (A6), SRAM2.19 (A6); also elsewhere on the board
A7: EEPROM0.4 (A7), SRAM0.18 (A7), SRAM2.18 (A7); also elsewhere on the board
A8: EEPROM0.29 (A8), SRAM0.8 (A8), SRAM2.8 (A8); also elsewhere on the board
A9: EEPROM0.28 (A9), SRAM0.7 (A9), SRAM2.7 (A9); also elsewhere on the board
A10: EEPROM0.24 (A10), SRAM0.6 (A10), SRAM2.6 (A10); also elsewhere on the board
A11: EEPROM0.27 (A11), SRAM0.5 (A11), SRAM2.5 (A11); also elsewhere on the board
A12: EEPROM0.3 (A12), SRAM0.4 (A12), SRAM2.4 (A12); also elsewhere on the board
A13: EEPROM0.30 (A13), SRAM0.3 (A13), SRAM2.3 (A13); also elsewhere on the board
A14: EEPROM0.2 (A14), SRAM0.2 (A14), SRAM2.2 (A14); also elsewhere on the board
A15: SRAM0.1 (A15), SRAM2.1 (A15); also elsewhere on the board
ABORTB: R23.1; also elsewhere on the board
BA0: SRAM0.48 (A16), SRAM2.48 (A16); also elsewhere on the board
BA1: SRAM0.17 (A17), SRAM2.17 (A17); also elsewhere on the board
BA2: SRAM0.16 (A18), SRAM2.16 (A18); also elsewhere on the board
BA3: SRAM0.9 (A19), SRAM2.9 (A19); also elsewhere on the board
BA4: SRAM0.45 (A20), SRAM2.45 (A20); also elsewhere on the board
BE: R22.1; also elsewhere on the board
D0: EEPROM0.13 (I/O0), IC7.11 (I), SRAM0.29 (DQ0), SRAM2.29 (DQ0); also elsewhere on the board
D0_3.3: IC7.12 (O); also elsewhere on the board
D1: EEPROM0.14 (I/O1), IC7.14 (I), SRAM0.31 (DQ1), SRAM2.31 (DQ1); also elsewhere on the board
D1_3.3: IC7.15 (O); also elsewhere on the board
D2: EEPROM0.15 (I/O2), IC10.7 (I), SRAM0.33 (DQ2), SRAM2.33 (DQ2); also elsewhere on the board
D2_3.3: IC10.6 (O); also elsewhere on the board
D3: EEPROM0.18 (I/O3), IC10.9 (I), SRAM0.35 (DQ3), SRAM2.35 (DQ3); also elsewhere on the board
D3_3.3: IC10.10 (O); also elsewhere on the board
D4: EEPROM0.19 (I/O4), IC10.3 (I), SRAM0.38 (DQ4), SRAM2.38 (DQ4); also elsewhere on the board
D4_3.3: IC10.2 (O); also elsewhere on the board
D5: EEPROM0.20 (I/O5), IC10.5 (I), SRAM0.40 (DQ5), SRAM2.40 (DQ5); also elsewhere on the board
D5_3.3: IC10.4 (O); also elsewhere on the board
D6: EEPROM0.21 (I/O6), IC10.11 (I), SRAM0.42 (DQ6), SRAM2.42 (DQ6); also elsewhere on the board
D6_3.3: IC10.12 (O); also elsewhere on the board
D7: EEPROM0.22 (I/O7), IC10.14 (I), SRAM0.44 (DQ7), SRAM2.44 (DQ7); also elsewhere on the board
D7_3.3: IC10.15 (O); also elsewhere on the board
GND: C1.2, C3.2, C11.2, C12.2, C13.2, C16.2, C17.2, C18.2, C19.2, C20.2, C21.2, C22.2, C23.2, C28.2, CN1.GND, EEPROM0.16 (GND), IC4.3 (GND), IC6.8 (VSS), IC7.8 (VSS), IC10.8 (VSS), NMI0.3, PWR_LED0.C, RST_SW0.3, SRAM0.27 (GND), SRAM0.46 (GND), SRAM0.47 (~BYTE), SRAM2.27 (GND), SRAM2.46 (GND), SRAM2.47 (~BYTE); also elsewhere on the board
MOSI: IC7.3 (I); also elsewhere on the board
MOSI_3.3: IC7.2 (O); also elsewhere on the board
unnamed: PWR_LED0.A, R11.2
RDY: R1.1; also elsewhere on the board
SD_CLK: IC7.5 (I); also elsewhere on the board
SD_CLK_3.3: IC7.4 (O); also elsewhere on the board
VCC: C1.1, C3.1, C11.1, C12.1, C13.1, C16.1, C17.1, C18.1, C19.1, C20.1, C21.1, C22.1, C23.1, C28.1, EEPROM0.31 (~WE), EEPROM0.32 (VCC), IC4.2 (+5V), R1.2, R4.2, R11.1, R22.2, R23.2, S1.1 (O), SRAM0.12 (CE2), SRAM0.37 (VCC), SRAM2.12 (CE2), SRAM2.37 (VCC); also elsewhere on the board
VIN: CN1.VBUS, S1.2
~NMI: NMI0.1 (S), R4.1; also elsewhere on the board
~RAM2_CS: SRAM2.26 (~CE), SRAM2.28 (~OE); also elsewhere on the board
~RAM_CS: SRAM0.26 (~CE), SRAM0.28 (~OE); also elsewhere on the board
~ROM_CS: EEPROM0.23 (~CE), EEPROM0.25 (~OE); also elsewhere on the board
~RST: IC4.1 (/RST), RST_SW0.1 (S); also elsewhere on the board
~SD_CS_3.3: IC7.6 (O); also elsewhere on the board
~SD_CS: IC7.7 (I); also elsewhere on the board
~V_CS_3.3: IC6.2 (O); also elsewhere on the board
~V_CS: IC6.3 (I); also elsewhere on the board
~WR: SRAM0.11 (~WE), SRAM2.11 (~WE); also elsewhere on the board

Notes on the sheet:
Memory ICs
Reset
Level shifting
Power
Bypass capacitors
Pull-ups

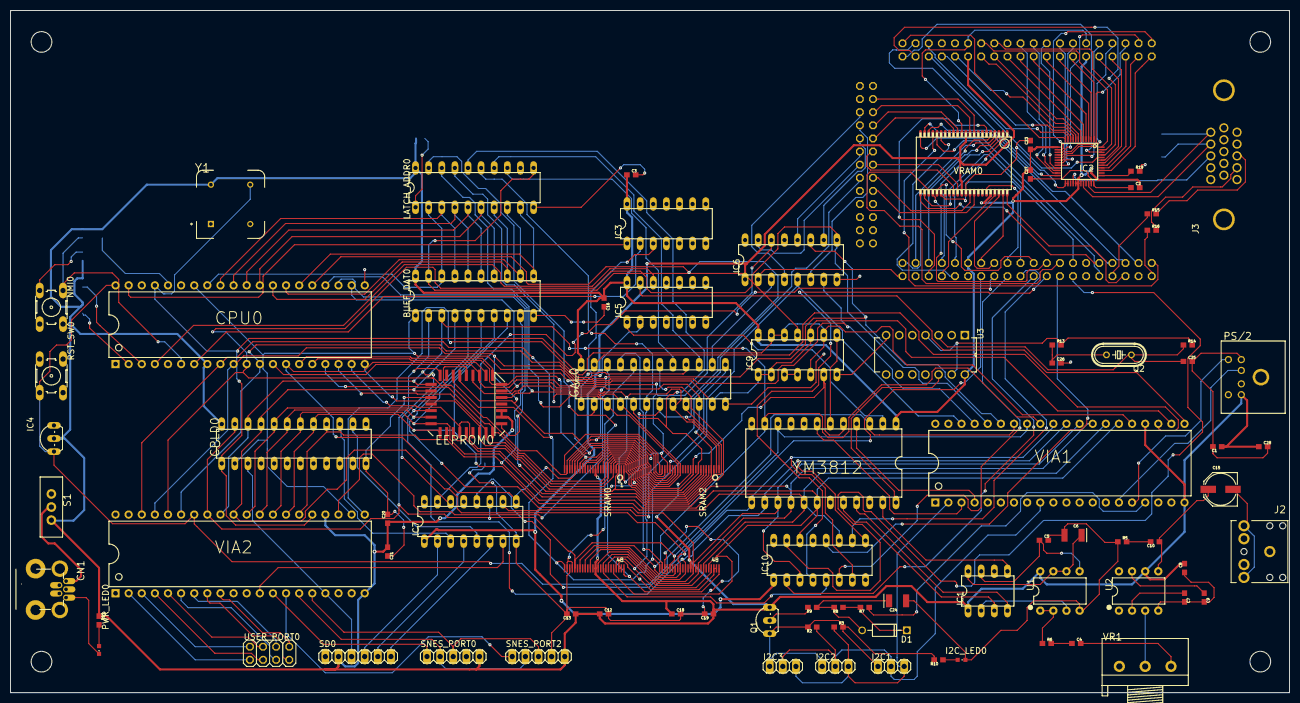
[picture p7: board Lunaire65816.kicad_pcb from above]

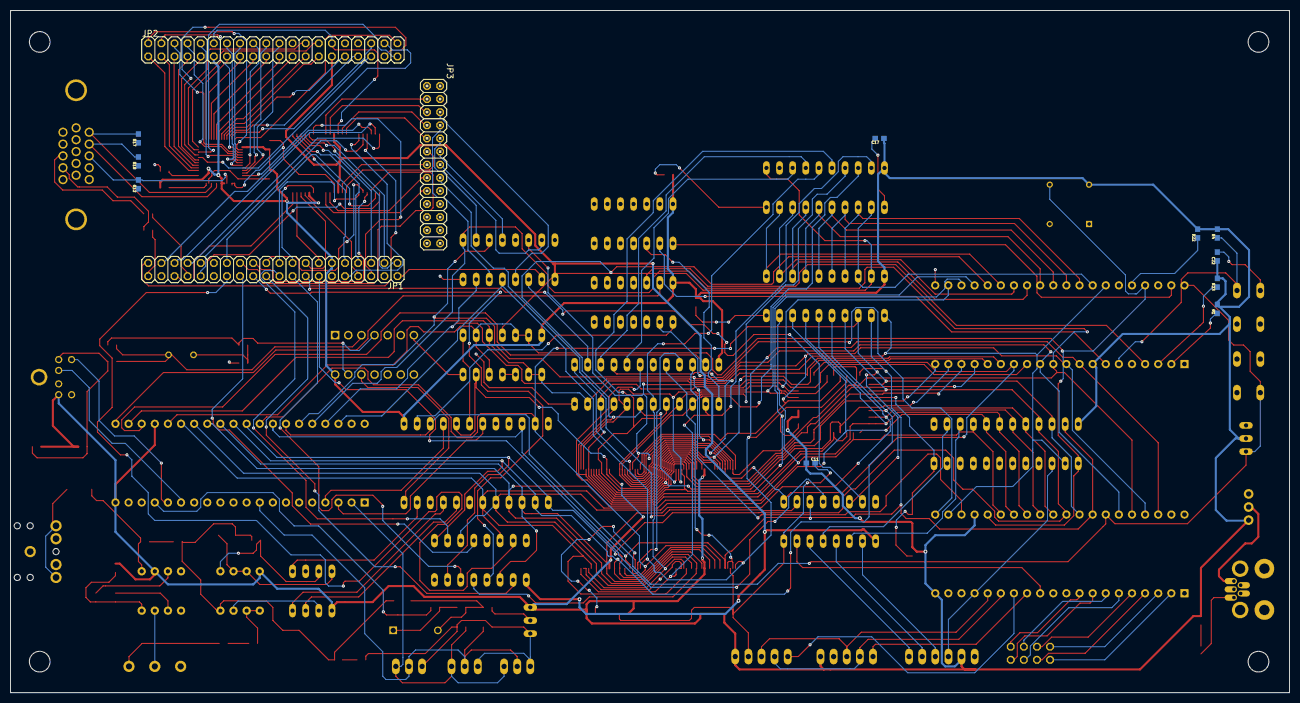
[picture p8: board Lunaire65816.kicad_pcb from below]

Board: 2 copper layers, 247.7 x 132.1 mm, 100 parts (13 on the bottom side), 209 nets.

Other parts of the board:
@HOLE0, @HOLE1, @HOLE2, @HOLE3: (no value)
